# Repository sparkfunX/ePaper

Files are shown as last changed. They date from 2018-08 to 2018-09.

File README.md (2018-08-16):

SparkFun 3 Color ePaper Displays
===========================================================
SparkX 3 Color ePaper Display - 1.54" (SPX-14892) (https://www.sparkfun.com/products/14892)

[*SparkX 3 Color ePaper Display - 1.54" (SPX-14892)*](https://www.sparkfun.com/products/14892)

Repository Contents
-------------------

* **/1.54in display** - Datasheets and board files for the 1.54" display
* **/4.2in display** - Datasheets for the 4.2" display
* **/7.5in display** - Datasheets for the 7.5" display
* **ePaper.lbr** - Eagle library for ePaper board components

License Information
-------------------

This product is _**open source**_! 

Please use, reuse, and modify these files as you see fit. Please maintain attribution to SparkFun Electronics and release anything derivative under the same license.

Distributed as-is; no warranty is given.

- Your friends at SparkFun.

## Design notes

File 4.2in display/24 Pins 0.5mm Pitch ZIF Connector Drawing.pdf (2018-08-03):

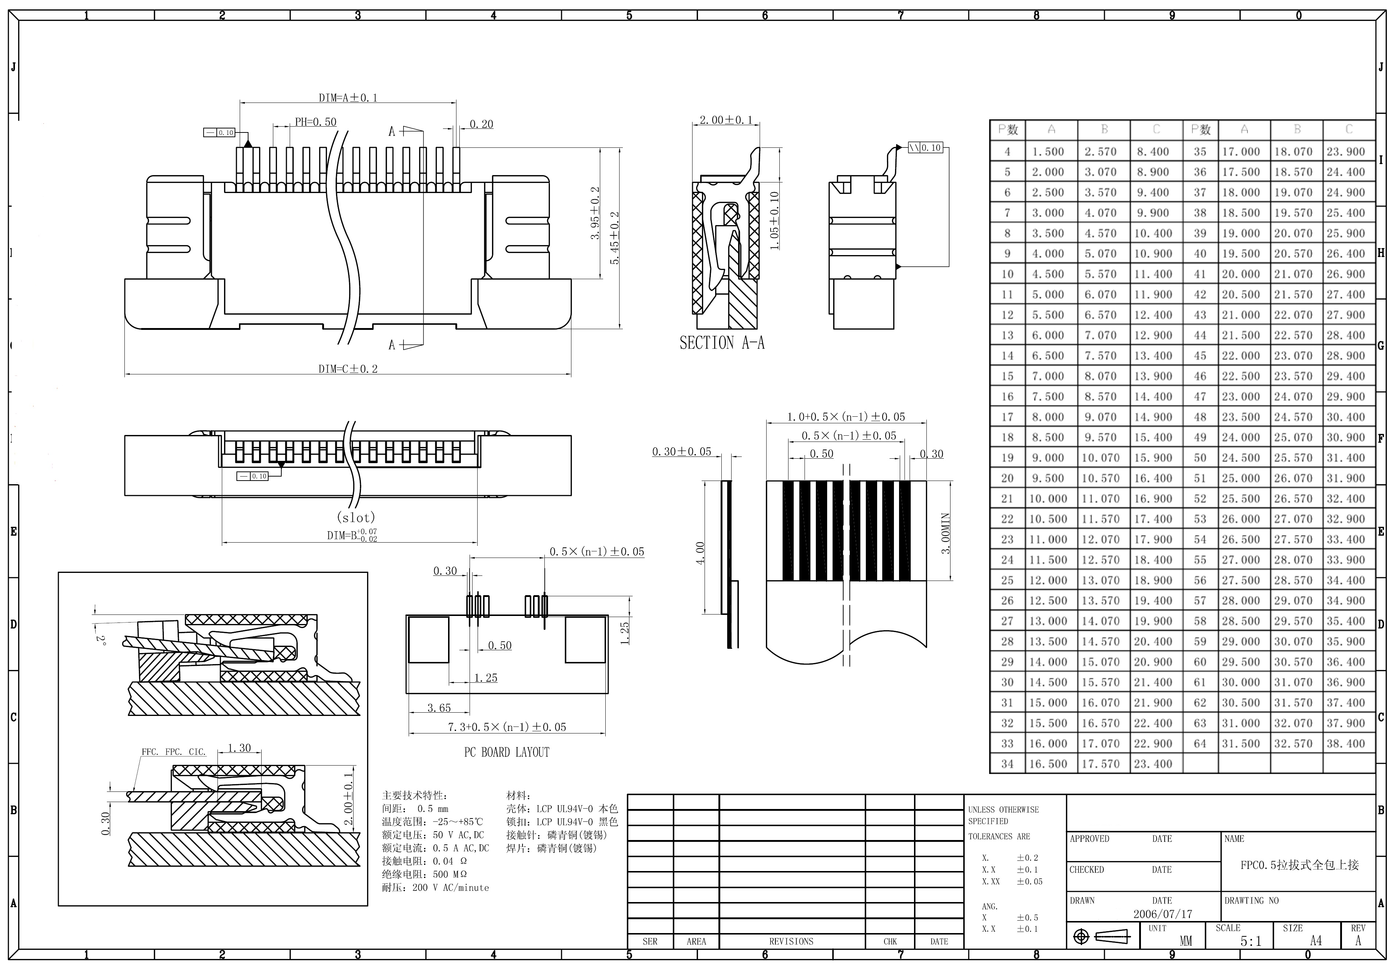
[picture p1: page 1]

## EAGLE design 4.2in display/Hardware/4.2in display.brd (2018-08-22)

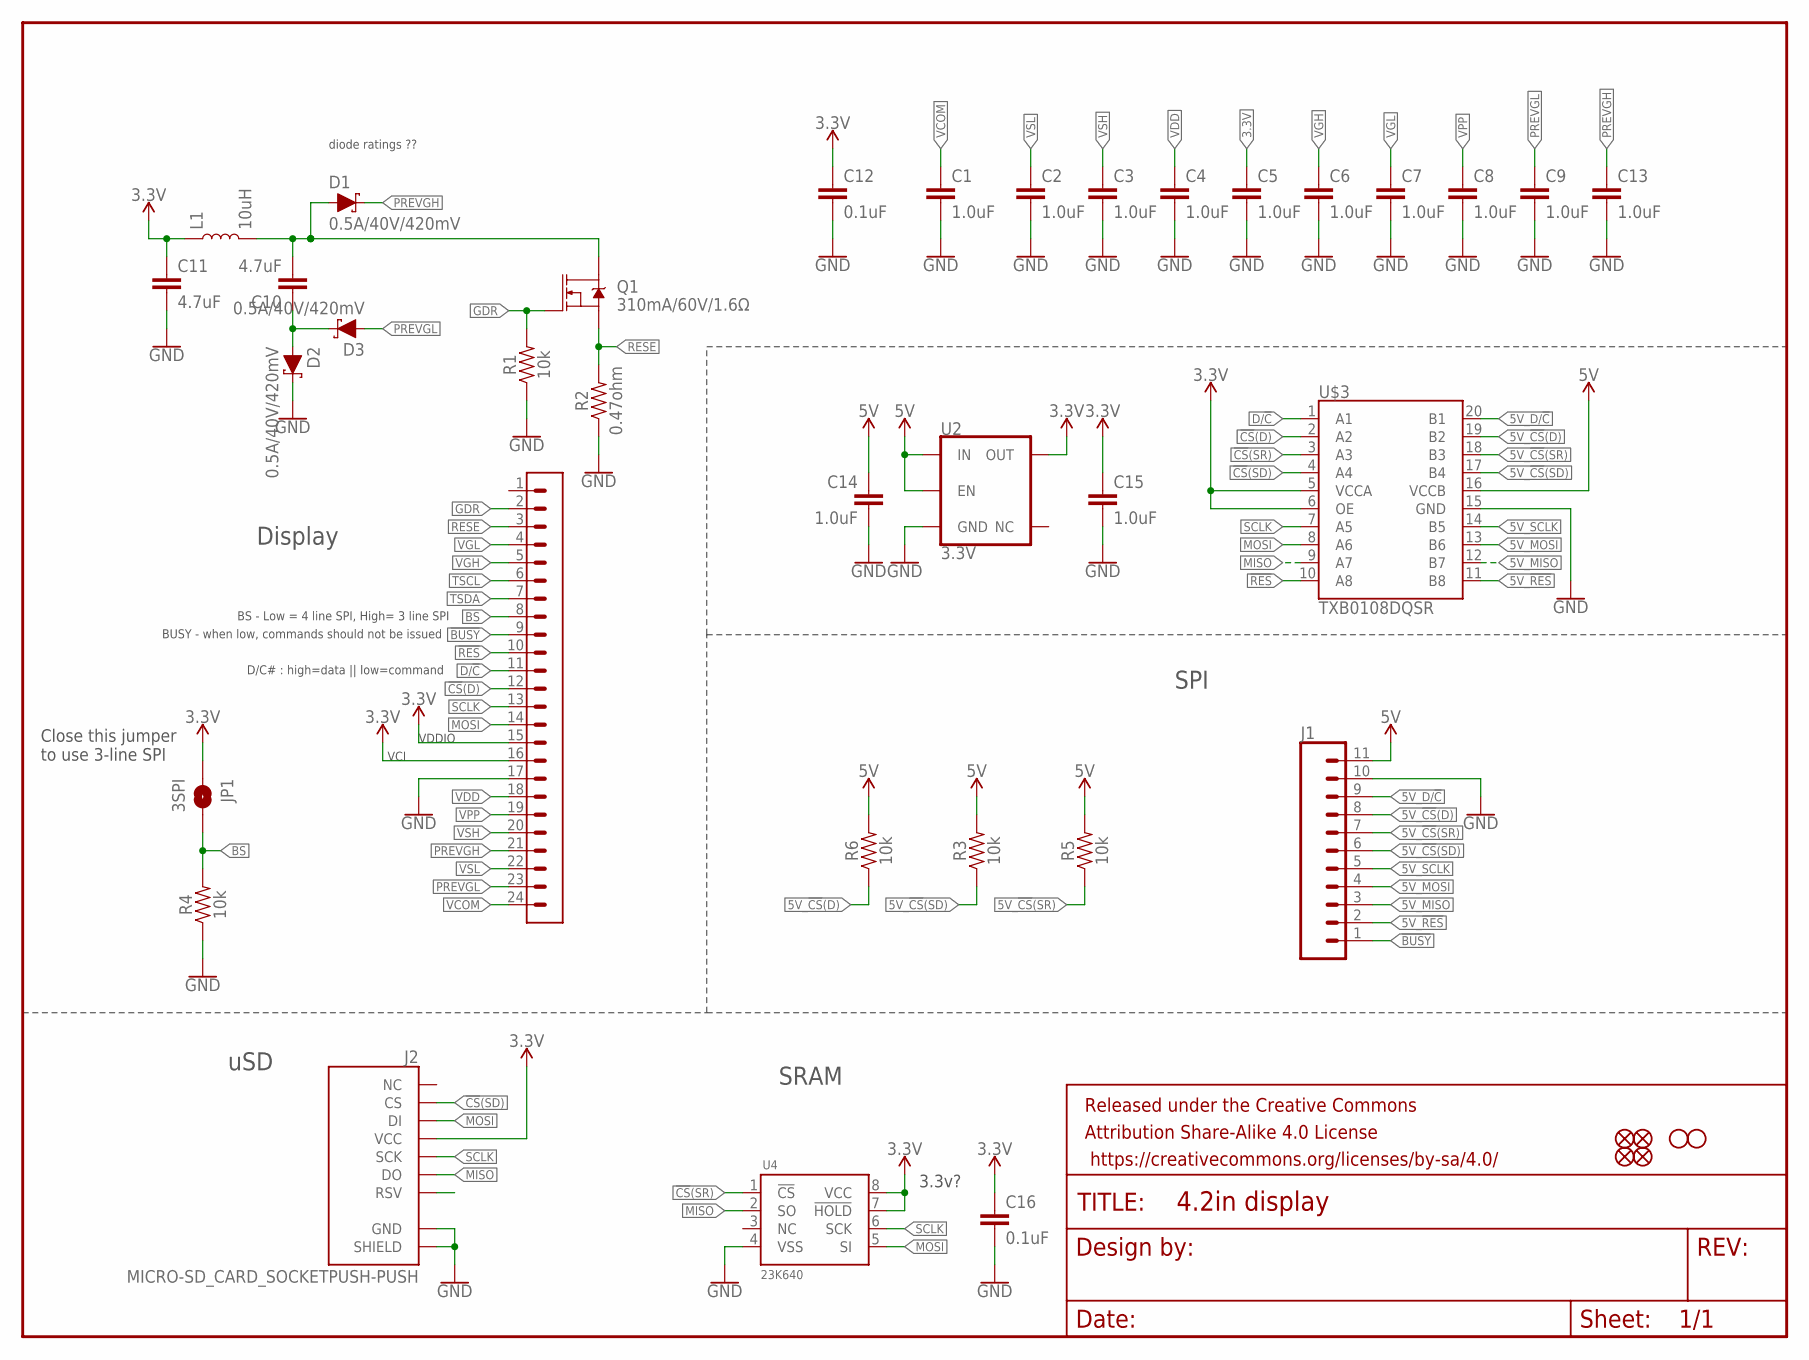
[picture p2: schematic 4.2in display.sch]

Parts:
C1, C14, C15: 1.0uF; 0603
C2, C3, C4, C5, C6, C7, C8, C9, C13: 1.0uF; 0805
C10, C11: 4.7uF; 0805
C12, C16: 0.1uF; 0603
D1, D2, D3: 0.5A/40V/420mV; SOD-323
FD1, FD2, FD3, FD4: FIDUCIALUFIDUCIAL; FIDUCIAL-MICRO
FRAME1: FRAME-LETTER; CREATIVE_COMMONS
H1, H2: STAND-OFF
J1: CONN_111X11_NO_SILK; 1X11_NO_SILK
J2: MICRO-SD_CARD_SOCKETPUSH-PUSH; MICRO-SD-SOCKET
JP1: 3SPI; SMT-JUMPER_2_NO_SILK
L1: 10uH; INDUCTOR_4.7UH
Q1: 310mA/60V/1.6Ω; SOT323
R1, R3, R4, R5, R6: 10k; 0603
R2: 0.47ohm; 0603
U2: 3.3V; SOT23-5
U4: 23K640; SO08
U$1: 24_PIN_FPC_0.5MM
U$3: TXB0108DQSR; UFDFN-20

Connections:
3.3V: C5.1, C11.1, C12.1, C15.1, C16.1, J2.VCC, JP1.1, L1.P$1 (1), U2.5 (OUT), U4.7 (!HOLD), U4.8 (VCC), U$1.15, U$1.16, U$3.5 (VCCA), U$3.6 (OE)
5V: C14.1, J1.11, R3.2, R5.2, R6.2, U2.1 (IN), U2.3 (EN), U$3.16 (VCCB)
5V_!CS!(D): J1.8, R6.1, U$3.19 (B2)
5V_!CS!(SD): J1.6, R3.1, U$3.17 (B4)
5V_!CS!(SR): J1.7, R5.1, U$3.18 (B3)
5V_!RES: J1.2, U$3.11 (B8)
5V_D/!C: J1.9, U$3.20 (B1)
5V_MISO: J1.3, U$3.12 (B7)
5V_MOSI: J1.4, U$3.13 (B6)
5V_SCLK: J1.5, U$3.14 (B5)
!BUSY: J1.1, U$1.9
!CS!(D): U$1.12, U$3.2 (A2)
!CS!(SD): J2.CS, U$3.4 (A4)
!CS!(SR): U4.1 (!CS), U$3.3 (A3)
!RES: U$1.10, U$3.10 (A8)
BS: JP1.2, R4.2, U$1.8
D/!C: U$1.11, U$3.1 (A1)
GDR: Q1.1 (G), R1.2, U$1.2
GND: C1.2, C2.2, C3.2, C4.2, C5.2, C6.2, C7.2, C8.2, C9.2, C11.2, C12.2, C13.2, C14.2, C15.2, C16.2, D2.C, J1.10, J2.CD1 (SHIELD), J2.GND, R1.1, R2.1, R4.1, U2.2 (GND), U4.4 (VSS), U$1.17, U$3.15 (GND)
MISO: J2.DO, U4.2 (SO), U$3.9 (A7)
MOSI: J2.DI, U4.5 (SI), U$1.14, U$3.8 (A6)
unnamed: C10.1, D2.A, D3.C
unnamed: C10.2, D1.A, L1.P$2 (2), Q1.3 (D)
PREVGH: C13.1, D1.C, U$1.21
PREVGL: C9.1, D3.A, U$1.23
RESE: Q1.2 (S), R2.2, U$1.3
SCLK: J2.SCLK (SCK), U4.6 (SCK), U$1.13, U$3.7 (A5)
TSCL: U$1.6
TSDA: U$1.7
VCOM: C1.1, U$1.24
VDD: C4.1, U$1.18
VGH: C6.1, U$1.5
VGL: C7.1, U$1.4
VPP: C8.1, U$1.19
VSH: C3.1, U$1.20
VSL: C2.1, U$1.22

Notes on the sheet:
D/C# : high=data || low=command
BUSY - when low, commands should not be issued
BS - Low = 4 line SPI, High= 3 line SPI
diode ratings ??
VDDIO
VCI
Display
SPI
uSD
3.3v?
Close this jumper to use 3-line SPI
SRAM

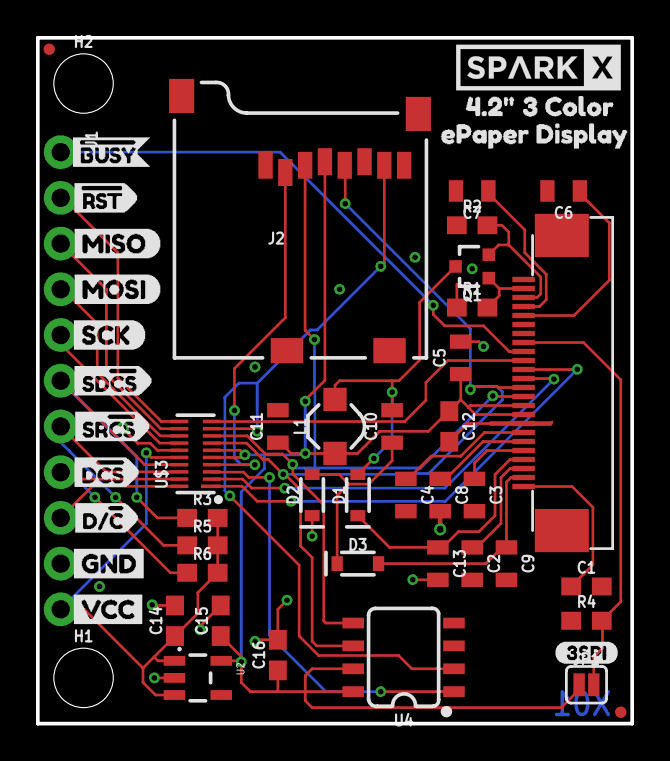
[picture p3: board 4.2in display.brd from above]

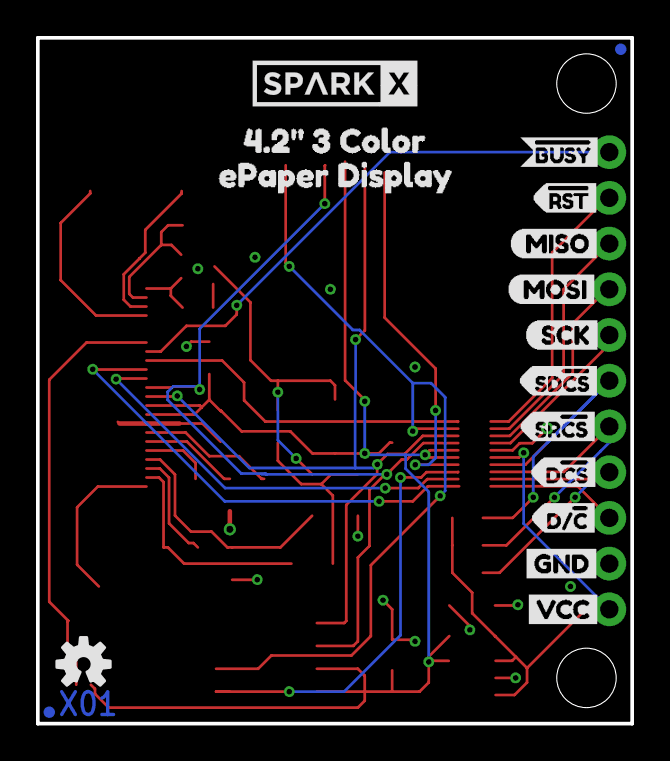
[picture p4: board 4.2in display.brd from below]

Board: 2 copper layers, 33.0 x 38.1 mm, 73 parts (18 on the bottom side), 34 nets.

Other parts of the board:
U$2: OSHW-LOGO-S
U$4: #BUSY0
U$5, U$18: SPARKX-LOGO4; SPARKX-MEDIUM
U$6: #BUSY1
U$7: D##C10
U$8: MISO1
U$9: D#CS2
U$10: SD#CS0
U$11: #RST1
U$12: 3SPI0
U$13, U$21: VCC9
U$14: GND9
U$15: SR#CS1
U$16: MOSI0
U$17: SCK2
U$19: 3_COLOR2
U$20: #RST2
U$22: 3_COLOR3
U$23: 4#2#0
U$24: MISO3
U$25: MOSI4
U$26: SCK5
U$27: SD#CS6
U$28: SR#CS7
U$29: D#CS8
U$30: D##C9
U$31: GND11
U$32: EPAPER_DISPLAY5
U$33: EPAPER_DISPLAY4
U$34: 4#2#1

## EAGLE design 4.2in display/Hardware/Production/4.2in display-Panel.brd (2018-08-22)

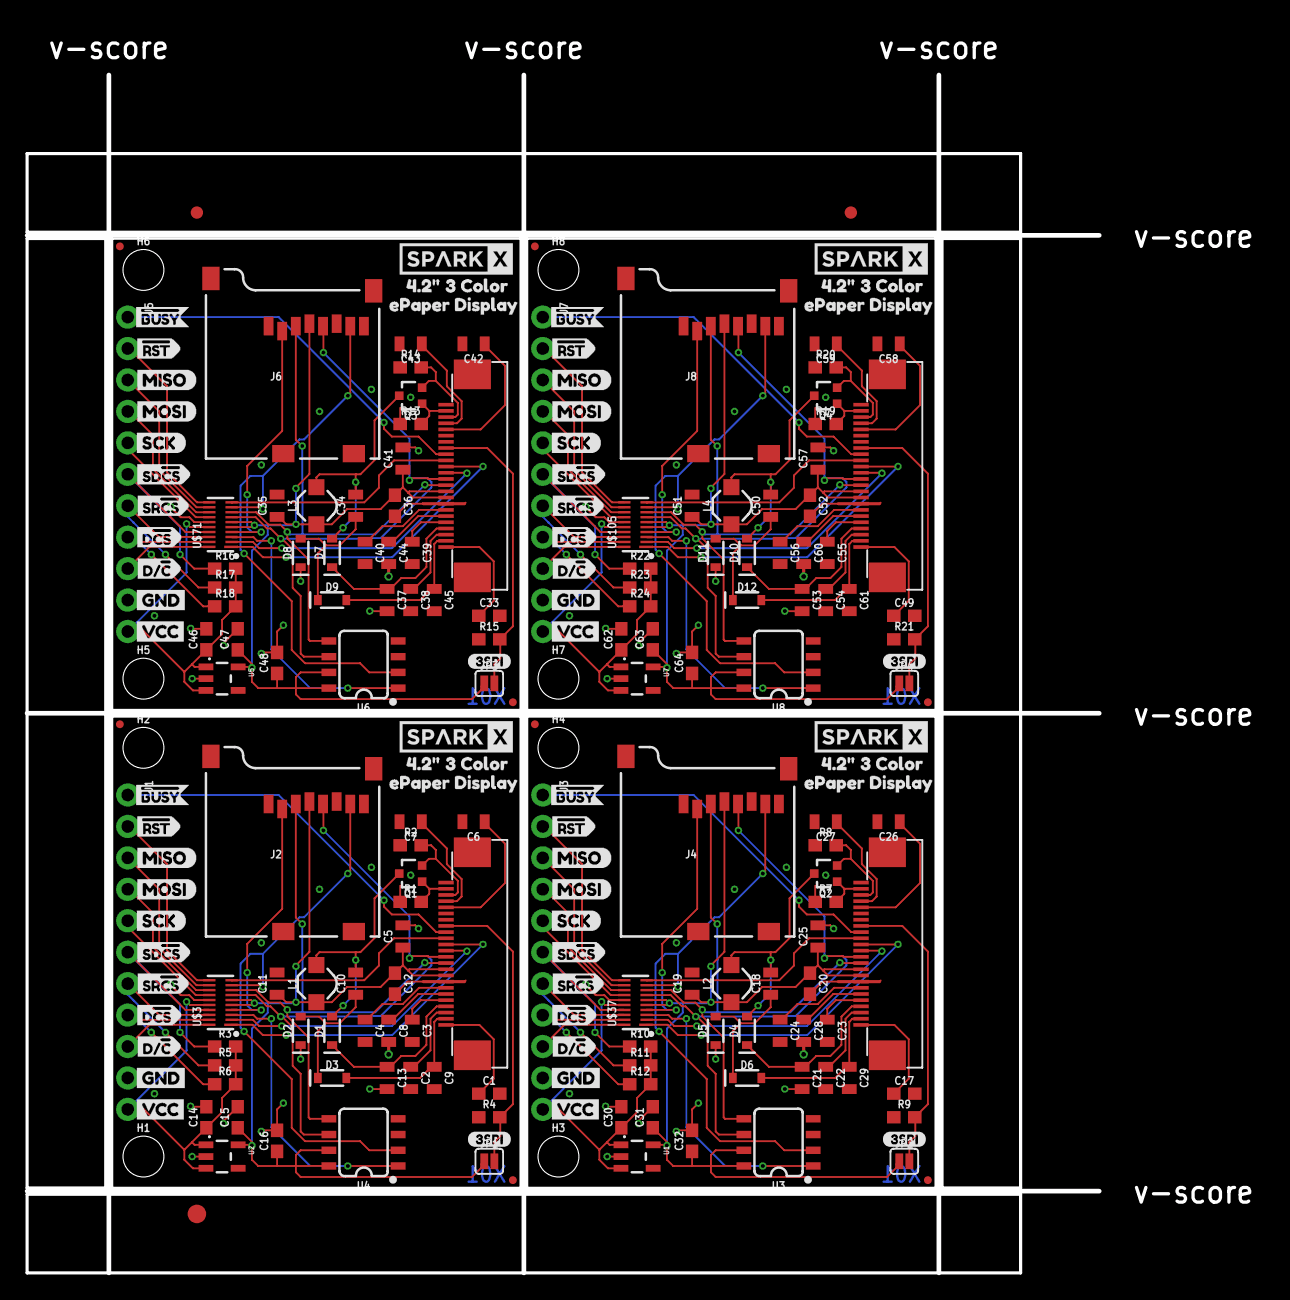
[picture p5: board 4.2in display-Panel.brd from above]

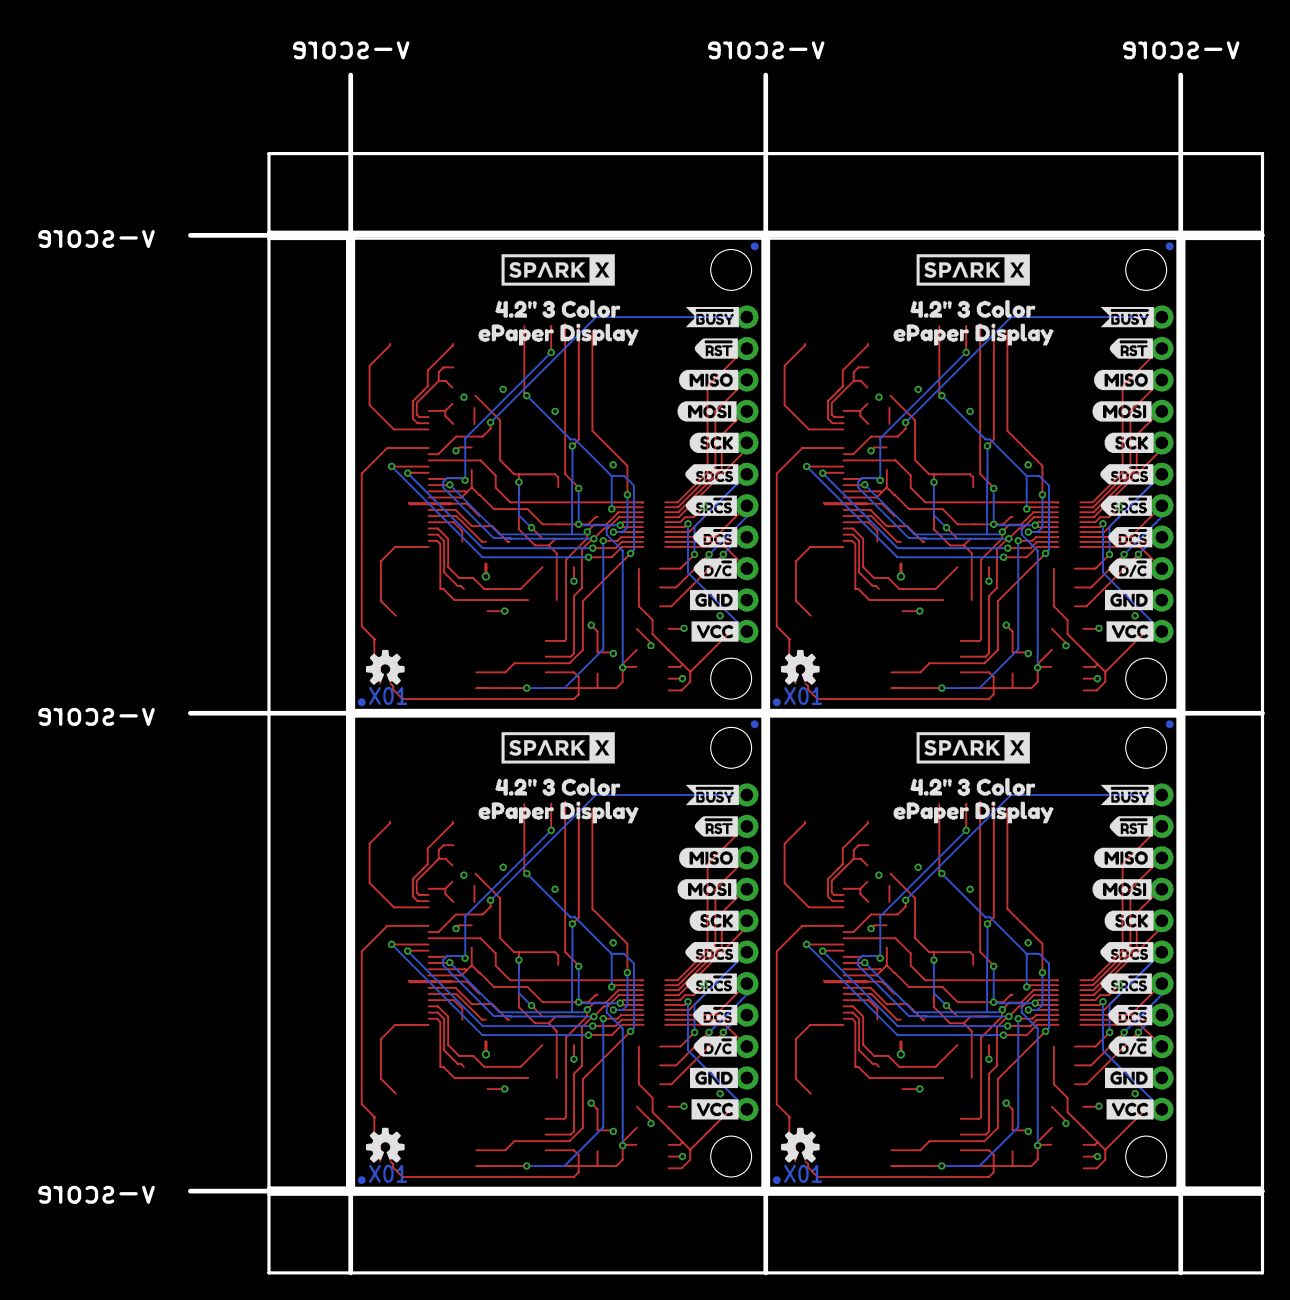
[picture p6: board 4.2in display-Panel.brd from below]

Board: 2 copper layers, 86.6 x 96.8 mm, 291 parts (72 on the bottom side), 136 nets.

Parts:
C1, C14, C15, C17, C30, C31, C33, C46, C47, C49, C62, C63: 1.0uF; 0603
C2, C3, C4, C5, C6, C7, C8, C9, C13, C21, C22, C23, C24, C25, C26, C27, C28, C29, C37, C38, C39, C40, C41, C42, C43, C44, C45, C53, C54, C55, C56, C57, C58, C59, C60, C61: 1.0uF; 0805
C10, C11, C18, C19, C34, C35, C50, C51: 4.7uF; 0805
C12, C16, C20, C32, C36, C48, C52, C64: 0.1uF; 0603
D1, D2, D3, D4, D5, D6, D7, D8, D9, D10, D11, D12: 0.5A/40V/420mV; SOD-323
E$1, E$2: FIDUCIAL-1X2
E$3: FIDUCIAL-1.5X3
FD1, FD2, FD3, FD4, FD5, FD6, FD7, FD8, FD9, FD10, FD11, FD12, FD13, FD14, FD15, FD16: FIDUCIALUFIDUCIAL; FIDUCIAL-MICRO
H1, H2, H3, H4, H5, H6, H7, H8: STAND-OFF
J1, J3, J5, J7: 1X11_NO_SILK
J2, J4, J6, J8: MICRO-SD_CARD_SOCKETPUSH-PUSH; MICRO-SD-SOCKET
JP1, JP2, JP3, JP4: 3SPI; SMT-JUMPER_2_NO_SILK
L1, L2, L3, L4: 10uH; INDUCTOR_4.7UH
Q1, Q2, Q3, Q4: 310mA/60V/1.6Ω; SOT323
R1, R3, R4, R5, R6, R7, R9, R10, R11, R12, R13, R15, R16, R17, R18, R19, R21, R22, R23, R24: 10k; 0603
R2, R8, R14, R20: 0.47ohm; 0603
U1, U2, U5, U7: 3.3V; SOT23-5
U3, U4, U6, U8: 23K640; SO08
U$1, U$35, U$69, U$103: 24_PIN_FPC_0.5MM
U$2, U$36, U$70, U$104: OSHW-LOGO-S
U$3, U$37, U$71, U$105: TXB0108DQSR; UFDFN-20
U$4, U$47, U$81, U$115: #BUSY0
U$5, U$18, U$48, U$62, U$82, U$96, U$116, U$130: SPARKX-LOGO4; SPARKX-MEDIUM
U$6, U$49, U$83, U$117: #BUSY1
U$7, U$38, U$72, U$106: D##C10
U$8, U$44, U$78, U$112: MISO1
U$9, U$41, U$75, U$109: D#CS2
U$10, U$42, U$76, U$110: SD#CS0
U$11, U$39, U$73, U$107: #RST1
U$12, U$59, U$93, U$127: 3SPI0
U$13, U$21, U$60, U$61, U$94, U$95, U$128, U$129: VCC9
U$14, U$40, U$74, U$108: GND9
U$15, U$43, U$77, U$111: SR#CS1
U$16, U$45, U$79, U$113: MOSI0
U$17, U$46, U$80, U$114: SCK2
U$19, U$63, U$97, U$131: 3_COLOR2
U$20, U$50, U$84, U$118: #RST2
U$22, U$64, U$98, U$132: 3_COLOR3
U$23, U$65, U$99, U$133: 4#2#0
U$24, U$51, U$85, U$119: MISO3
U$25, U$52, U$86, U$120: MOSI4
U$26, U$53, U$87, U$121: SCK5
U$27, U$54, U$88, U$122: SD#CS6
U$28, U$55, U$89, U$123: SR#CS7
U$29, U$56, U$90, U$124: D#CS8
U$30, U$57, U$91, U$125: D##C9
U$31, U$58, U$92, U$126: GND11
U$32, U$67, U$101, U$135: EPAPER_DISPLAY5
U$33, U$66, U$100, U$134: EPAPER_DISPLAY4
U$34, U$68, U$102, U$136: 4#2#1

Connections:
3.3V: C5.1, C11.1, C12.1, C15.1, C16.1, J2.VCC, JP1.1, L1.P$1, U2.5, U4.7, U4.8, U$1.15, U$1.16, U$3.5, U$3.6
3.3V1: C19.1, C20.1, C25.1, C31.1, C32.1, J4.VCC, JP2.1, L2.P$1, U1.5, U3.7, U3.8, U$35.15, U$35.16, U$37.5, U$37.6
3.3V2: C35.1, C36.1, C41.1, C47.1, C48.1, J6.VCC, JP3.1, L3.P$1, U5.5, U6.7, U6.8, U$69.15, U$69.16, U$71.5, U$71.6
3.3V3: C51.1, C52.1, C57.1, C63.1, C64.1, J8.VCC, JP4.1, L4.P$1, U7.5, U8.7, U8.8, U$103.15, U$103.16, U$105.5, U$105.6
5V: C14.1, J1.11, R3.2, R5.2, R6.2, U2.1, U2.3, U$3.16
5V1: C30.1, J3.11, R10.2, R11.2, R12.2, U1.1, U1.3, U$37.16
5V2: C46.1, J5.11, R16.2, R17.2, R18.2, U5.1, U5.3, U$71.16
5V3: C62.1, J7.11, R22.2, R23.2, R24.2, U7.1, U7.3, U$105.16
5V_!CS!(D): J1.8, R6.1, U$3.19
5V_!CS!(D)1: J3.8, R12.1, U$37.19
5V_!CS!(D)2: J5.8, R18.1, U$71.19
5V_!CS!(D)3: J7.8, R24.1, U$105.19
5V_!CS!(SD): J1.6, R3.1, U$3.17
5V_!CS!(SD)1: J3.6, R10.1, U$37.17
5V_!CS!(SD)2: J5.6, R16.1, U$71.17
5V_!CS!(SD)3: J7.6, R22.1, U$105.17
5V_!CS!(SR): J1.7, R5.1, U$3.18
5V_!CS!(SR)1: J3.7, R11.1, U$37.18
5V_!CS!(SR)2: J5.7, R17.1, U$71.18
5V_!CS!(SR)3: J7.7, R23.1, U$105.18
5V_!RES: J1.2, U$3.11
5V_!RES1: J3.2, U$37.11
5V_!RES2: J5.2, U$71.11
5V_!RES3: J7.2, U$105.11
5V_D/!C: J1.9, U$3.20
5V_D/!C1: J3.9, U$37.20
5V_D/!C2: J5.9, U$71.20
5V_D/!C3: J7.9, U$105.20
5V_MISO: J1.3, U$3.12
5V_MISO1: J3.3, U$37.12
5V_MISO2: J5.3, U$71.12
5V_MISO3: J7.3, U$105.12
5V_MOSI: J1.4, U$3.13
5V_MOSI1: J3.4, U$37.13
5V_MOSI2: J5.4, U$71.13
5V_MOSI3: J7.4, U$105.13
5V_SCLK: J1.5, U$3.14
5V_SCLK1: J3.5, U$37.14
5V_SCLK2: J5.5, U$71.14
5V_SCLK3: J7.5, U$105.14
!BUSY: J1.1, U$1.9
!BUSY1: J3.1, U$35.9
!BUSY2: J5.1, U$69.9
!BUSY3: J7.1, U$103.9
!CS!(D): U$1.12, U$3.2
!CS!(D)1: U$35.12, U$37.2
!CS!(D)2: U$69.12, U$71.2
!CS!(D)3: U$103.12, U$105.2
!CS!(SD): J2.CS, U$3.4
!CS!(SD)1: J4.CS, U$37.4
!CS!(SD)2: J6.CS, U$71.4
!CS!(SD)3: J8.CS, U$105.4
!CS!(SR): U4.1, U$3.3
!CS!(SR)1: U3.1, U$37.3
!CS!(SR)2: U6.1, U$71.3
!CS!(SR)3: U8.1, U$105.3
!RES: U$1.10, U$3.10
!RES1: U$35.10, U$37.10
!RES2: U$69.10, U$71.10
!RES3: U$103.10, U$105.10
BS: JP1.2, R4.2, U$1.8
BS1: JP2.2, R9.2, U$35.8
BS2: JP3.2, R15.2, U$69.8
BS3: JP4.2, R21.2, U$103.8
D/!C: U$1.11, U$3.1
D/!C1: U$35.11, U$37.1
D/!C2: U$69.11, U$71.1
D/!C3: U$103.11, U$105.1
GDR: Q1.1, R1.2, U$1.2
GDR1: Q2.1, R7.2, U$35.2
GDR2: Q3.1, R13.2, U$69.2
GDR3: Q4.1, R19.2, U$103.2
GND: C1.2, C2.2, C3.2, C4.2, C5.2, C6.2, C7.2, C8.2, C9.2, C11.2, C12.2, C13.2, C14.2, C15.2, C16.2, D2.C, J1.10, J2.CD1, J2.GND, R1.1, R2.1, R4.1, U2.2, U4.4, U$1.17, U$3.15
GND1: C17.2, C19.2, C20.2, C21.2, C22.2, C23.2, C24.2, C25.2, C26.2, C27.2, C28.2, C29.2, C30.2, C31.2, C32.2, D5.C, J3.10, J4.CD1, J4.GND, R7.1, R8.1, R9.1, U1.2, U3.4, U$35.17, U$37.15
GND2: C33.2, C35.2, C36.2, C37.2, C38.2, C39.2, C40.2, C41.2, C42.2, C43.2, C44.2, C45.2, C46.2, C47.2, C48.2, D8.C, J5.10, J6.CD1, J6.GND, R13.1, R14.1, R15.1, U5.2, U6.4, U$69.17, U$71.15
GND3: C49.2, C51.2, C52.2, C53.2, C54.2, C55.2, C56.2, C57.2, C58.2, C59.2, C60.2, C61.2, C62.2, C63.2, C64.2, D11.C, J7.10, J8.CD1, J8.GND, R19.1, R20.1, R21.1, U7.2, U8.4, U$103.17, U$105.15
MISO: J2.DO, U4.2, U$3.9
MISO1: J4.DO, U3.2, U$37.9
MISO2: J6.DO, U6.2, U$71.9
MISO3: J8.DO, U8.2, U$105.9
MOSI: J2.DI, U4.5, U$1.14, U$3.8
MOSI1: J4.DI, U3.5, U$35.14, U$37.8
MOSI2: J6.DI, U6.5, U$69.14, U$71.8
MOSI3: J8.DI, U8.5, U$103.14, U$105.8
unnamed: C18.1, D5.A, D6.C
unnamed: C10.1, D2.A, D3.C
unnamed: C18.2, D4.A, L2.P$2, Q2.3
unnamed: C10.2, D1.A, L1.P$2, Q1.3
unnamed: C34.1, D8.A, D9.C
unnamed: C34.2, D7.A, L3.P$2, Q3.3
unnamed: C50.1, D11.A, D12.C
unnamed: C50.2, D10.A, L4.P$2, Q4.3
PREVGH: C13.1, D1.C, U$1.21
PREVGH1: C21.1, D4.C, U$35.21
PREVGH2: C37.1, D7.C, U$69.21
PREVGH3: C53.1, D10.C, U$103.21
PREVGL: C9.1, D3.A, U$1.23
PREVGL1: C29.1, D6.A, U$35.23
PREVGL2: C45.1, D9.A, U$69.23
PREVGL3: C61.1, D12.A, U$103.23
RESE: Q1.2, R2.2, U$1.3
RESE1: Q2.2, R8.2, U$35.3
RESE2: Q3.2, R14.2, U$69.3
RESE3: Q4.2, R20.2, U$103.3
SCLK: J2.SCLK, U4.6, U$1.13, U$3.7
SCLK1: J4.SCLK, U3.6, U$35.13, U$37.7
SCLK2: J6.SCLK, U6.6, U$69.13, U$71.7
SCLK3: J8.SCLK, U8.6, U$103.13, U$105.7
VCOM: C1.1, U$1.24
VCOM1: C17.1, U$35.24
VCOM2: C33.1, U$69.24
VCOM3: C49.1, U$103.24
VDD: C4.1, U$1.18
VDD1: C24.1, U$35.18
VDD2: C40.1, U$69.18
VDD3: C56.1, U$103.18
VGH: C6.1, U$1.5
VGH1: C26.1, U$35.5
VGH2: C42.1, U$69.5
VGH3: C58.1, U$103.5
VGL: C7.1, U$1.4
VGL1: C27.1, U$35.4
VGL2: C43.1, U$69.4
VGL3: C59.1, U$103.4
VPP: C8.1, U$1.19
VPP1: C28.1, U$35.19
VPP2: C44.1, U$69.19
VPP3: C60.1, U$103.19
VSH: C3.1, U$1.20
VSH1: C23.1, U$35.20
VSH2: C39.1, U$69.20
VSH3: C55.1, U$103.20
VSL: C2.1, U$1.22
VSL1: C22.1, U$35.22
VSL2: C38.1, U$69.22
VSL3: C54.1, U$103.22

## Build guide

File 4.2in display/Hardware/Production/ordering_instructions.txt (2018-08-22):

panel size, 81x91mm
PCB thickness, 1.6mm
number of layers, 2
soldermask color, Black
silkscreen color, White
oz copper, 1oz
finish, HASL lead free
stencils, top+bottom
pcs per panel, 4

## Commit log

2018-08-16 add datasheets
    [1.54in.brd]
2018-08-22 minor rev
    [1.54in-Panel.brd, 1.54in.brd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]
2018-08-22 added boards
    [4.2in display-Panel.GBL, 4.2in display-Panel.GBO, 4.2in display-Panel.GBS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]
2018-09-18 rmv old
    [display adapter.brd, display adapter.sch]
2018-09-25 Revert "asm"
    This reverts commit 79dfb80ccaf4c70f6c8d653a0d6d0867a03f4c3a.
    [4.2in display.brd, 4.2in display.sch]
2018-10-09 Revert "Revert "asm""
    This reverts commit b489ea2ff6e59cc2c3bae19cf3fe86e4ee51237d.
    [4.2in display.brd, 4.2in display.sch]
2018-10-09 Revert "Revert "Revert "asm"""
    This reverts commit 13aa5e244575f702f785403d246ecc40f8071a55.
    [4.2in display.brd, 4.2in display.sch]
2018-10-09 Revert "sch"
    This reverts commit 65ffcdcff918ffc3cbfeebb47afa4d674ba5142f.
    [4.2in display.sch]
2018-10-09 4.2 schematic update
    [4.2in display.sch]

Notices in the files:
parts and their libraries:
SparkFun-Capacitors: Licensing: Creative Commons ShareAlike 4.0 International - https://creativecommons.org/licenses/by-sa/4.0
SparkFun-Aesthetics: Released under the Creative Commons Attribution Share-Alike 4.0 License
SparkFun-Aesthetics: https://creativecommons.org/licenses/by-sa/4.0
